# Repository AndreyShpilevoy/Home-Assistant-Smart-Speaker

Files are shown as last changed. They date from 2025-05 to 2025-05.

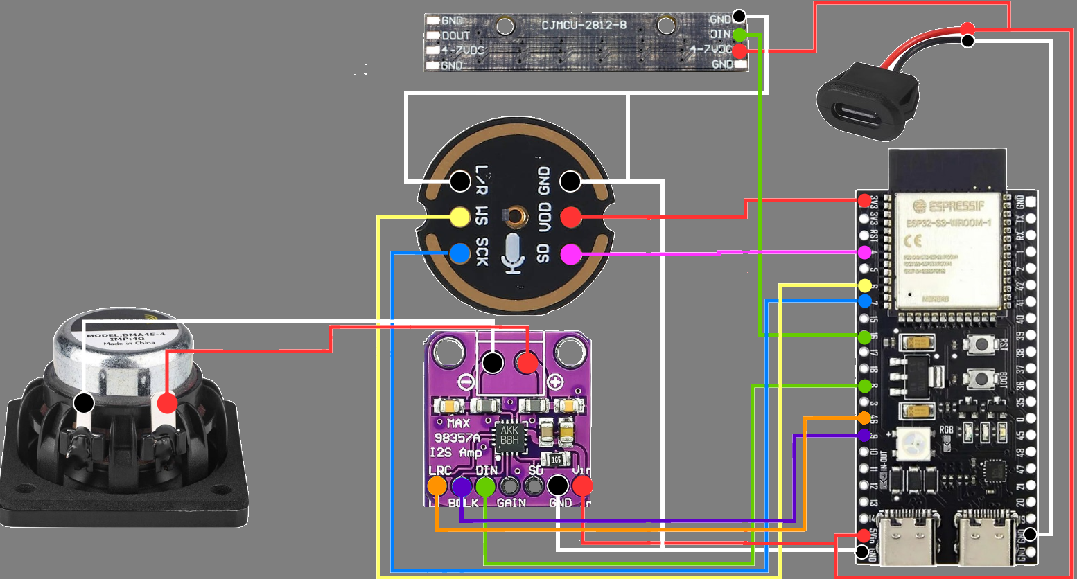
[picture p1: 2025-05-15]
schem/media_player_schematic_gry-bg.png

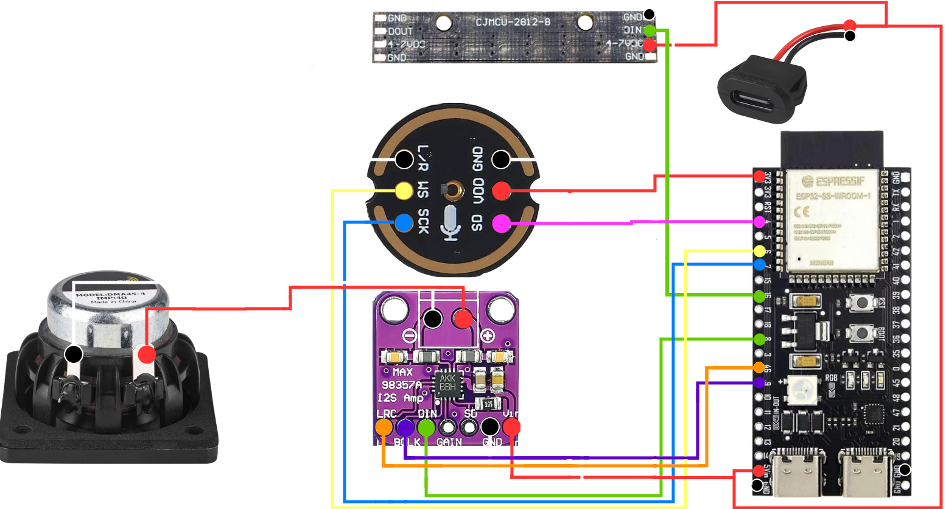
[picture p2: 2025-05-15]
schem/media_player_schematic.png

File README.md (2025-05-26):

# Why

Original repo is great, but a bit out of date. To compile the code you need to do some troubleshouting. Figure out which version of platform use, select specific PR for external component. Also in my case even after all this changes - volume control was still broken. Volume was always on 100%.

# Main advantages

- Up-to-date (for now)
- Code compeletely rewritten. Code *Home Assistant Voice: Preview Edition* (https://github.com/esphome/home-assistant-voice-pe) was used as base
    - Working volume regulator
    - Working timers
    - Sound effects for events: mute on/off, wake word triggered, timer and error
    - Stop wake word can be used to stop answer
    - Removed unused devices (mini-jack, factory_reset)
- Led actions was adopted to hardware
- 2 settings for day and night brightness on LED strip (day/night hours are configurable)
- Added 5 ADC buttons (Play/Pause, Volume UP, Volume DOWN, Interrupt VA, Mute) and 6 events (Interrupt VA + Mute = Mute mic only)
- Added chema for ADC buttons array. Also added LID, but it's WIP and made for *12x12 SMD Push Button* and 2x8cm *Porotype Soldering board*

# Changes in comparison with the original repo:

- Schema changes
    - Max98357 connected to 5v instead of 3.3v (not necessary, only if you want to have louder sound)
- Script changes
    - Removed external_components
    - `speaker` and `media_player` replaced with standard ones
    - Added `mixer` and `resampler` to allow `media_player` to utilize a single output `speaker`
    - The original LED effects were too bright for me, changed it
    - Removed idle effect
    - Removed onboard LED (it was used for debug only anyway)
    - Code compeletely rewritten. Code *Home Assistant Voice: Preview Edition* (https://github.com/esphome/home-assistant-voice-pe) was used as base

# If Max98357 is too loud/quiet, you can adjust Gain
GAIN is, well, the gain setting. You can have a gain of 3dB, 6dB, 9dB, 12dB or 15dB.

- 15dB if a 100K resistor is connected between GAIN and GND
- 12dB if GAIN is connected directly to GND
- 9dB if GAIN is not connected to anything (this is the default)
- 6dB if GAIN is connected directly to Vin
- 3dB if a 100K resistor is connected between GAIN and Vin

# ORIGINAL READ ME
# Home Assistant Voice Assistant Smart Speaker

In the search for an "easy" Voice Assistant I ran across a lot of different implementations, many of which were confusing or left out key information needed. I decided to use an ESP32-S3-DevKitC-1-N8R2 Development Board. I finally found a Blog (https://tristam.ie/2024/1126/) that helped at least get a Voice Assistant up and running the only problem was, it wasn't a media_player. A lot of the work here is based on that work, except the Yaml file. I spent some time reviewing available working speakers including purchasing the ESP32-Box-S3 as an example of something that worked and finally came up with something that "works". It's still a work in progress, but I can play music on it, announcements, and it's working fairly well. Note: This is a Work in progress, not a finished project.  

# Files in the repo

- README.md - This readme
- schem (folder) - Contains a png wiring schematic for those who like a visual representation. This was taken from the aforementioned blog and edited.
- YAML (folder) - This contains the current working yaml for ESPHome in Home Assistant
- 3D Print - This contains the stl files to 3D print a box to place the components in. Currently, it is based on a remix (https://www.printables.com/model/982104-esp32-s3-esphome-voice-assistant-with-local-wake-w) of the original (https://www.printables.com/model/967157-esp32-s3-esphome-voice-assistant-with-local-wake-w) my plan is to not leave these unedited for long and make assembly more intuitive. 

# Parts list (Amazon - US)

- ESP32 Boards - [https://www.amazon.com/gp/product/B0C9H7Y66W](https://www.amazon.com/gp/product/B0C9H7Y66W?th=1)
- Omni directional Microphone (INMP441) - [https://www.amazon.com/gp/product/B09X3216DN](https://www.amazon.com/gp/product/B09X3216DN)
- Amplifier (MAX98357 3W) - [https://www.amazon.com/gp/product/B0CDWXZZCH](https://www.amazon.com/gp/product/B0CDWXZZCH)
- Speaker (Dayton Audio DMA45-4 1-1/2") - [https://www.amazon.com/gp/product/B07N1YW3SV](https://www.amazon.com/gp/product/B07N1YW3SV)
- Light Bar (Black WS2812B 5050 LED Light Stick) - [https://www.amazon.com/gp/product/B0D7CC469B](https://www.amazon.com/gp/product/B0D7CC469B)
- USB-C Connector - [https://www.amazon.com/gp/product/B0D7CN4BTV/](https://www.amazon.com/gp/product/B0D7CN4BTV/)

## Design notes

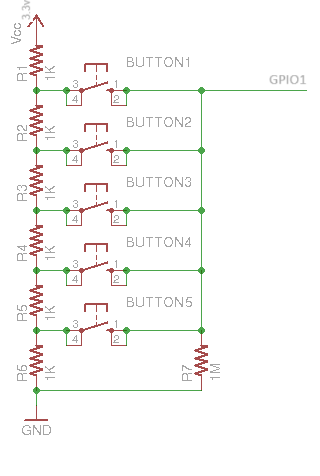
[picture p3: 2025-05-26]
schem/buttons_schematic.png

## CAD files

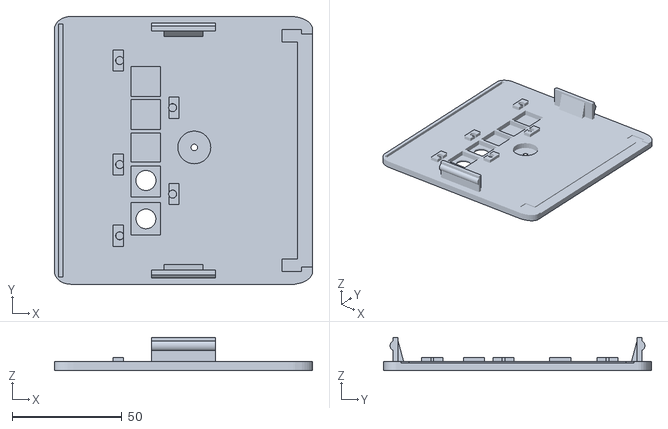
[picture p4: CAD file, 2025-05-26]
3D Print/Speaker-Enclosure-Lid-Buttons_WIP.stl
117.7 x 122.0 x 15.1

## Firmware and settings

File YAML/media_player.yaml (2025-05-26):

substitutions:
  name: esp32-voice-assistant-01
  friendly_name: ESP32-Voice-Assistant-01
  device_description: "ESP32 Voice Assistant Media Speaker"
  
  api_key: "ReplaceMe"
  ap_password: "ReplaceMe"
  ota_password: "ReplaceMe"
  
  #pins
  # I2S Audio SPK
  i2s_lrclk_pin_out: GPIO46
  i2s_bclk_pin_out: GPIO9
  i2s_dout_pin_spk: GPIO8

  # I2S AUdio MIC
  i2s_lrclk_pin_in: GPIO6
  i2s_bclk_pin_in: GPIO7
  i2s_din_pin_mic: GPIO4

  #Led's  
  led_pin: GPIO48 # on-board LED
  led_bar_pin: GPIO16 # Light Bar LED

  min_brightness_night: '0.11'
  max_brightness_night: '0.21'
  min_brightness_day: '0.60'
  max_brightness_day: '0.80'

  min_brightness_night_percent: 11%
  max_brightness_night_percent: 21%
  min_brightness_day_percent: 60%
  max_brightness_day_percent: 80%

  button_pin: GPIO1

  timezone: "Europe/Amsterdam"

  psramMode: octal #2MB PSRAM = quad mode, 8MB or 16MB = octal

  # Phases of the Voice Assistant
  # The voice assistant is ready to be triggered by a wake word
  voice_assist_idle_phase_id: '1'
  # The voice assistant is waiting for a voice command (after being triggered by the wake word)
  voice_assist_waiting_for_command_phase_id: '2'
  # The voice assistant is listening for a voice command
  voice_assist_listening_for_command_phase_id: '3'
  # The voice assistant is currently processing the command
  voice_assist_thinking_phase_id: '4'
  # The voice assistant is replying to the command
  voice_assist_replying_phase_id: '5'
  # The voice assistant is not ready
  voice_assist_not_ready_phase_id: '10'
  # The voice assistant encountered an error
  voice_assist_error_phase_id: '11'
  # # MUTED: The voice assistant is muted and will not reply to a wake-word
  # voice_assist_muted_phase_id: '12'
  # Change this to true in case you have a hidden SSID at home.
  hidden_ssid: "false"

esphome:
  name: ${name}
  friendly_name: ${friendly_name}
  comment: ${device_description}
  min_version: 2025.5.0
  on_boot:
    priority: 375
    then:
      # Run the script to refresh the LED status
      - script.execute: control_leds
      - delay: 1s
      # If after 10 minutes, the device is still initializing (It did not yet connect to Home Assistant), turn off the init_in_progress variable and run the script to refresh the LED status
      - delay: 10min
      - if:
          condition:
            lambda: return id(init_in_progress);
          then:
            - lambda: id(init_in_progress) = false;
            - script.execute: control_leds

esp32:
  board: esp32-s3-devkitc-1
  cpu_frequency: 240MHz
  variant: esp32s3
  flash_size: 16MB
  framework:
    type: esp-idf
    version: recommended
    sdkconfig_options:
      CONFIG_ESP32S3_DATA_CACHE_64KB: "y"
      CONFIG_ESP32S3_DATA_CACHE_LINE_64B: "y"
      CONFIG_ESP32S3_INSTRUCTION_CACHE_32KB: "y"

      # Moves instructions and read only data from flash into PSRAM on boot.
      # Both enabled allows instructions to execute while a flash operation is in progress without needing to be placed in IRAM.
      # Considerably speeds up mWW at the cost of using more PSRAM.
      CONFIG_SPIRAM_RODATA: "y"
      CONFIG_SPIRAM_FETCH_INSTRUCTIONS: "y"

      CONFIG_BT_ALLOCATION_FROM_SPIRAM_FIRST: "y"
      CONFIG_BT_BLE_DYNAMIC_ENV_MEMORY: "y"

      CONFIG_MBEDTLS_EXTERNAL_MEM_ALLOC: "y"
      CONFIG_MBEDTLS_SSL_PROTO_TLS1_3: "y"  # TLS1.3 support isn't enabled by default in IDF 5.1.5

wifi:
  id: wifi_id
  fast_connect: ${hidden_ssid}
  ssid: !secret wifi_ssid
  password: !secret wifi_password
  power_save_mode: none
  on_connect:
    - script.execute: control_leds
  on_disconnect:
    - script.execute: control_leds

network:
  enable_ipv6: true

logger:
  level: DEBUG
  logs:
    sensor: WARN  # avoids logging debug sensor updates

api:
  encryption:
    key: ${api_key}
  id: api_id
  on_client_connected:
    - script.execute: control_leds
  on_client_disconnected:
    - script.execute: control_leds

ota:
  - platform: esphome
    id: ota_esphome
    password: ${ota_password}

psram:
  mode: ${psramMode}
  speed: 80MHz

time:
  - platform: homeassistant
    id: ha_time
    timezone: ${timezone}
interval:
  - interval: 60sec
    then:
      - if:
          condition:
            lambda: return (id(ha_time).now().hour > int(id(day_switch_time).state) && id(ha_time).now().hour < int(id(night_switch_time).state));
          then:
            - lambda: id(min_brightness) = ${min_brightness_day};
            - lambda: id(max_brightness) = ${max_brightness_day};
          else:
            - lambda: id(min_brightness) = ${min_brightness_night};
            - lambda: id(max_brightness) = ${max_brightness_night};
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

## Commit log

2025-05-17 Fixed issues with time based brightnes. Added timezone setting. Added few sound notifications on wake word triggered, mute on/off fixed issue with instant ducking
    [media_player.yaml]
2025-05-17 Fixing minor inconsistencies Start/stop ducking are refactored
    [media_player.yaml]
2025-05-24 changed wake-word behaviour added stop wakeword to interrupt VA anounce
2025-05-24 added timer sound
2025-05-26 added ADC buttons (5 buttons and 6 actions)
    [Speaker-Enclosure-Lid-Buttons_WIP.stl]
